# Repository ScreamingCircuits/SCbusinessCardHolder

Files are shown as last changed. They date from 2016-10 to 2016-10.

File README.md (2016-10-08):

# SCbusinessCardHolder
Screaming Circuits business card holder, V2.1

The Screaming Circuits business card holder is a multi-function device intended for your amusement and as a demonstration of our workmanship.

After soldering in the pin headers, attaching the rubber feet, and inserting the batteries, it’s ready to go. Place it on your desk and put about ten business cards in. When someone takes a card (or if you pound on your keyboard hard enough) some of the LEDs will flash.

If you tip it up, so that the LEDs run along the bottom, it will act as a spirit level, and as a short ruler. It’s not angle calibrated. Doing so is up to you. 

The microcontroller fitted is of the Microchip PIC18F46K22 family. The initial version was produced with a PIC18F43K22 – the same, but with less FLASH and SRAM. The accelerometer is a Freescale MMA8452Q. The schematic and layout were created with EagleCAD. The code was written and compiled with Microchip XC8 in Mplab-X.

One of the pin headers is connected to the I2C and SPI bus pins on the MCU. The other is connected to the Microchip ICSP (in circuit serial programming) pins on the MCU. Button Usr 1 is connected to I/O pin RB4, and Usr 2 is connected to RB5.

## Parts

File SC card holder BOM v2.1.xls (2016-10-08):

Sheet: BOM
Item # | Qty | Ref Des | Manufacturer | Manf part num | DigiKey Part number | Description | Package | Type | Side | Notes | Qty 1 | $ Ext | Qty 550 | Qty needed @550 | Ord Qty | $ Ext
1 | 1 | U1 | Microchip | PIC18F43K22-I/MV | PIC18F43K22-I/MV-ND | MCU | UQFN40 | BGA | Top |  | 2.29 | 2.29 | 1.9 | 550 | 600 | 1140.00
2 | 1 | U2 | Freescale | MMA8452QR1 | MMA8452QR1CT-ND | Accelerometer | QFN16 | BGA | Top |  | 1.43 | 1.43 | 1.02 | 550 | 600 | 612.00
3 | 10 | D1, D3, D5, D7, D9, D11, D13, D15, D17, D19 | Panasonic | LNJ247W82RA | LNJ247W82RACT-ND | LED red | 0402 | SMT | Top |  | 0.46 | 4.60 | 0.0936 | 5500 | 6000 | 561.60
4 | 9 | D2, D4, D6, D8, D10, D12, D14, D16, D18 | Panasonic | LNJ347W83RA | LNJ347W83RACT-ND | LED green | 0402 | SMT | Top |  | 0.46 | 4.14 | 0.0936 | 4950 | 5500 | 514.80
5 | 5 | C1, C2, C3, C4, C5 | Taiyo | LMK105BJ104KV-F | 587-1227-1-ND | .1uf | 0402 | SMT | Top |  | 0.10 | 0.50 | 0.00325 | 2750 | 3000 | 9.75
6 | 1 | C6 | Samsung | CL05A475MQ5NRNC | 1276-1056-1-ND | 4.7uf | 0402 | SMT | Top |  | 0.21 | 0.21 | 0.0485 | 550 | 600 | 29.10
7 | 19 | R1-R19 | Stackpole | RMCF0402JT180R | RMCF0402JT180RCT-ND | 180 ohms | 0402 | SMT | Top |  | 0.10 | 1.90 | 0.00173 | 10450 | 12000 | 20.76
8 | 3 | R20, R21, R22 | Stackpole | RMCF0402JT10K0 | RMCF0402JT10K0CT-ND | 10K | 0402 | SMT | Top |  | 0.10 | 0.30 | 0.00328 | 1650 | 2000 | 6.56
9 | 1 | S1 | C&K Components | JS202011SCQN | 401-2002-1-ND | DPDT switch |  | SMT | Top |  | 0.46 | 0.46 | 0.3031 | 550 | 500 | 151.55
10 | 2 | S2, S3 | C&K Components | PTS645SK50SMTR92 LFS | CKN9087CT-ND | Momentary push |  | SMT | Top |  | 0.25 | 0.50 | 0.13125 | 1100 | 1200 | 157.50
11 | 2 | B1, B2 | MPD | BK-883 | BK-883-ND | 2032 holder |  | SMT | Bottom |  | 0.35 | 0.70 | 0.2448 | 1100 | 1200 | 293.76
12 | 2 | H1, H2 | Sullins | PREC006SFAN-RC | S1212EC-06-ND | 1x6 header ICSP |  | DNS | Top |  | 0.20 | 0.40 | 0.11586 | 1100 | 1200 | 139.03
13 | 4 | F1, F2, F3, F4 | 3M | SJ61A1 | SJ5746-0-ND | Rubber foot |  | DNS | Bottom |  | 0.10 | 0.39 | 0.0787 | 2200 | 2400 | 188.88
14 | 2 | Batt1, Batt2 | Energizer | CR2032VP | N189-ND | CR2032 battery |  | DNS | Bottom |  | 0.33 | 0.66 | 0.18411 | 1100 | 1200 | 220.93
 |  |  |  |  |  | PCB 3.5" x 1.65" |  |  |  |  |  | 0.00
 |  |  |  |  |  |  |  |  |  |  | Total parts, Qty 1 | 18.48 |  | Total parts, Qty 550 | 7.36 | 4046.22
 | Blue = purchase, but don't install |  |  |  |  |  |  | Assembly quote summary
 |  |  |  |  |  |  | BOM line items | 11
 | Note that item #13, the 3M feet only come in sheets of 144 |  |  |  |  |  | BGA | 2
 |  |  |  |  |  |  | SMT | 52
 |  |  |  |  |  |  | Thru-hole | 0
 |  |  |  |  |  |  | Total | 54

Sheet: LED
System V | 3
Diode drop | 0.385
 | 2.615
LED V | 1.95
C | 0.0036 | Max LED C | 0.0828
R V | 0.665
R Ohm | 184.7222222

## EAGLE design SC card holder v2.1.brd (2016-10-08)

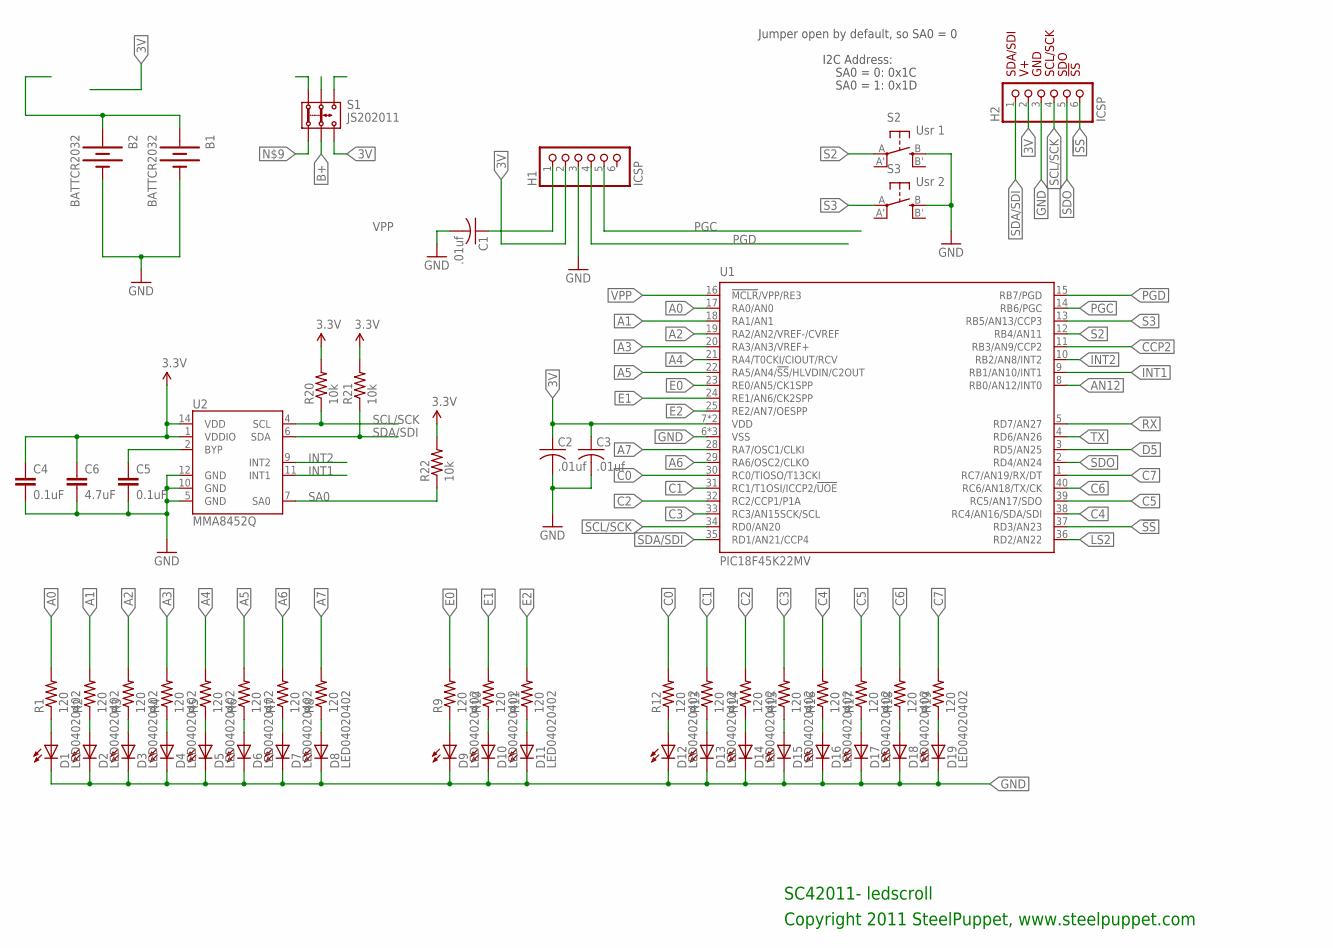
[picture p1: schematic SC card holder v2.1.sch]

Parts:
B1, B2: BATTCR2032; BATT_2032_SMT
C1, C2, C3: .01uf; C0402K
C4, C5: 0.1uF; 0402-CAP
C6: 4.7uF; 0402-CAP
D1, D2, D3, D4, D5, D6, D7, D8, D9, D10, D11, D12, D13, D14, D15, D16, D17, D18, D19: LED04020402; LED0402
H1, H2: ICSP; 1X06-S
R1, R2, R3, R4, R5, R6, R7, R8, R9, R10, R11, R12, R13, R14, R15, R16, R17, R18, R19: 120; R0402
R20, R21, R22: 10k; 0402-RES
S1: JS202011; JS202011SMT
S2: Usr 1; EVQ-Q2
S3: Usr 2; EVQ-Q2
U1: PIC18F45K22MV; QFN40-5X5
U2: MMA8452Q; QFN-16_0.5MM

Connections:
3V: C2.1, C3.1, C4.1, C6.1, H1.2, H2.2, R20.2, R21.2, R22.2, S1.3 (3.2), S1.4 (3.1), U1.7 (VDD), U1.26 (VDD), U2.1 (VDDIO), U2.14 (VDD)
!SS: H2.6, U1.37 (RD3/AN23)
A0: R1.2, U1.17 (RA0/AN0)
A1: R2.2, U1.18 (RA1/AN1)
A2: R3.2, U1.19 (RA2/AN2/VREF-/CVREF)
A3: R4.2, U1.20 (RA3/AN3/VREF+)
A4: R5.2, U1.21 (RA4/T0CKI/CIOUT/RCV)
A5: R6.2, U1.22 (RA5/AN4/!SS!/HLVDIN/C2OUT)
A6: R7.2, U1.29 (RA6/OSC2/CLKO)
A7: R8.2, U1.28 (RA7/OSC1/CLKI)
AN12: U1.8 (RB0/AN12/INT0)
B+: B1.1 (+), B1.3 (+), B2.1 (+), B2.3 (+), S1.2 (2.2), S1.5 (2.1)
BYP: C5.1, U2.2 (BYP)
C0: R12.2, U1.30 (RC0/TIOSO/T13CKI)
C1: R13.2, U1.31 (RC1/T1OSI/ICCP2/!UOE)
C2: R14.2, U1.32 (RC2/CCP1/P1A)
C3: R15.2, U1.33 (RC3/AN15SCK/SCL)
C4: R16.2, U1.38 (RC4/AN16/SDA/SDI)
C5: R17.2, U1.39 (RC5/AN17/SDO)
C6: R18.2, U1.40 (RC6/AN18/TX/CK)
C7: R19.2, U1.1 (RC7/AN19/RX/DT)
CCP2: U1.11 (RB3/AN9/CCP2)
D5: U1.3 (RD5/AN25)
E0: R9.2, U1.23 (RE0/AN5/CK1SPP)
E1: R10.2, U1.24 (RE1/AN6/CK2SPP)
E2: R11.2, U1.25 (RE2/AN7/OESPP)
GND: B1.2 (-), B2.2 (-), C1.2, C2.2, C3.2, C4.2, C5.2, C6.2, D1.C, D2.C, D3.C, D4.C, D5.C, D6.C, D7.C, D8.C, D9.C, D10.C, D11.C, D12.C, D13.C, D14.C, D15.C, D16.C, D17.C, D18.C, D19.C, H1.3, H2.3, S2.B (S), S3.B (S), U1.6 (VSS), U1.27 (VSS), U1.41 (VSS), U2.5 (GND), U2.10 (GND), U2.12 (GND)
INT1: U1.9 (RB1/AN10/INT1), U2.11 (INT1)
INT2: U1.10 (RB2/AN8/INT2), U2.9 (INT2)
LS2: U1.36 (RD2/AN22)
unnamed: D1.A, R1.1
unnamed: D2.A, R2.1
unnamed: D3.A, R3.1
unnamed: D4.A, R4.1
unnamed: D9.A, R9.1
unnamed: D10.A, R10.1
unnamed: D11.A, R11.1
unnamed: D13.A, R13.1
unnamed: D14.A, R14.1
unnamed: D15.A, R15.1
unnamed: D12.A, R12.1
unnamed: D6.A, R6.1
unnamed: D7.A, R7.1
unnamed: D16.A, R16.1
unnamed: D17.A, R17.1
unnamed: D8.A, R8.1
unnamed: D5.A, R5.1
unnamed: D18.A, R18.1
unnamed: D19.A, R19.1
PGC: H1.5, U1.14 (RB6/PGC)
PGD: H1.4, U1.15 (RB7/PGD)
RX: U1.5 (RD7/AN27)
S2: S2.A, U1.12 (RB4/AN11)
S3: S3.A, U1.13 (RB5/AN13/CCP3)
SA0: R22.1, U2.7 (SA0)
SCL/SCK: H2.4, R20.1, U1.34 (RD0/AN20), U2.4 (SCL)
SDA/SDI: H2.1, R21.1, U1.35 (RD1/AN21/CCP4), U2.6 (SDA)
SDO: H2.5, U1.2 (RD4/AN24)
TX: U1.4 (RD6/AN26)
VPP: C1.1, H1.1, U1.16 (!MCLR!/VPP/RE3)

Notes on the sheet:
SC42011- ledscroll
Copyright 2011 SteelPuppet, www.steelpuppet.com
SDA/SDI
GND
SCL/SCK
SDO
!SS
I2C Address:
SA0 = 0: 0x1C
SA0 = 1: 0x1D
Jumper open by default, so SA0 = 0

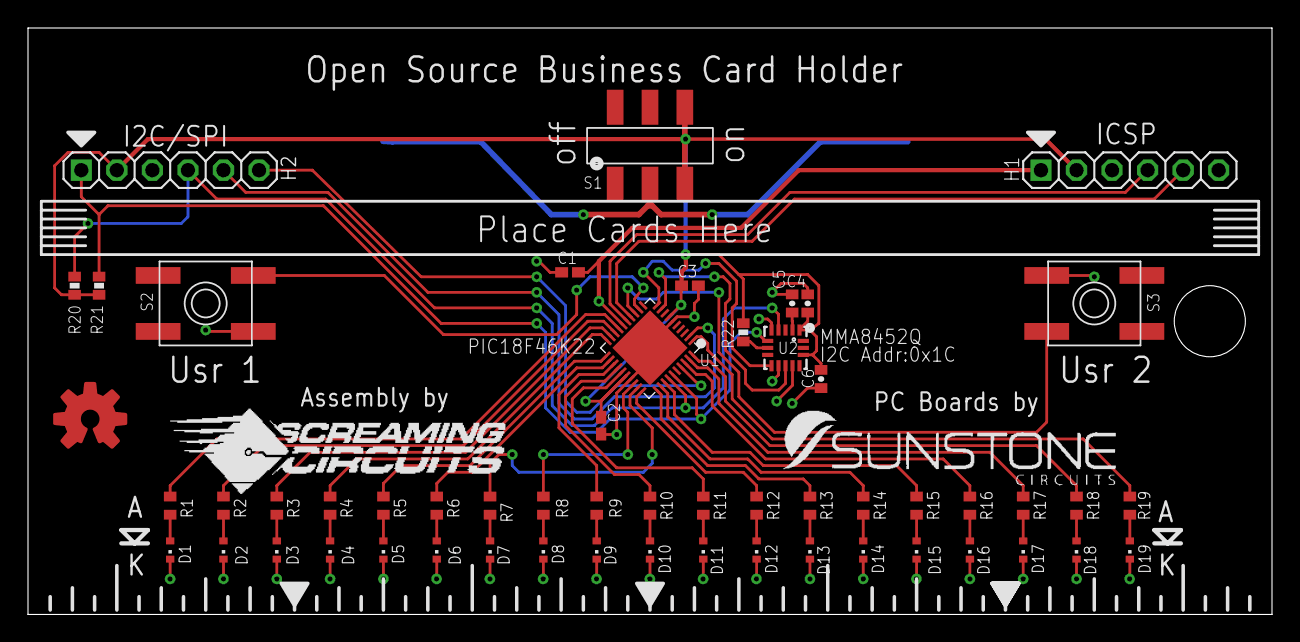
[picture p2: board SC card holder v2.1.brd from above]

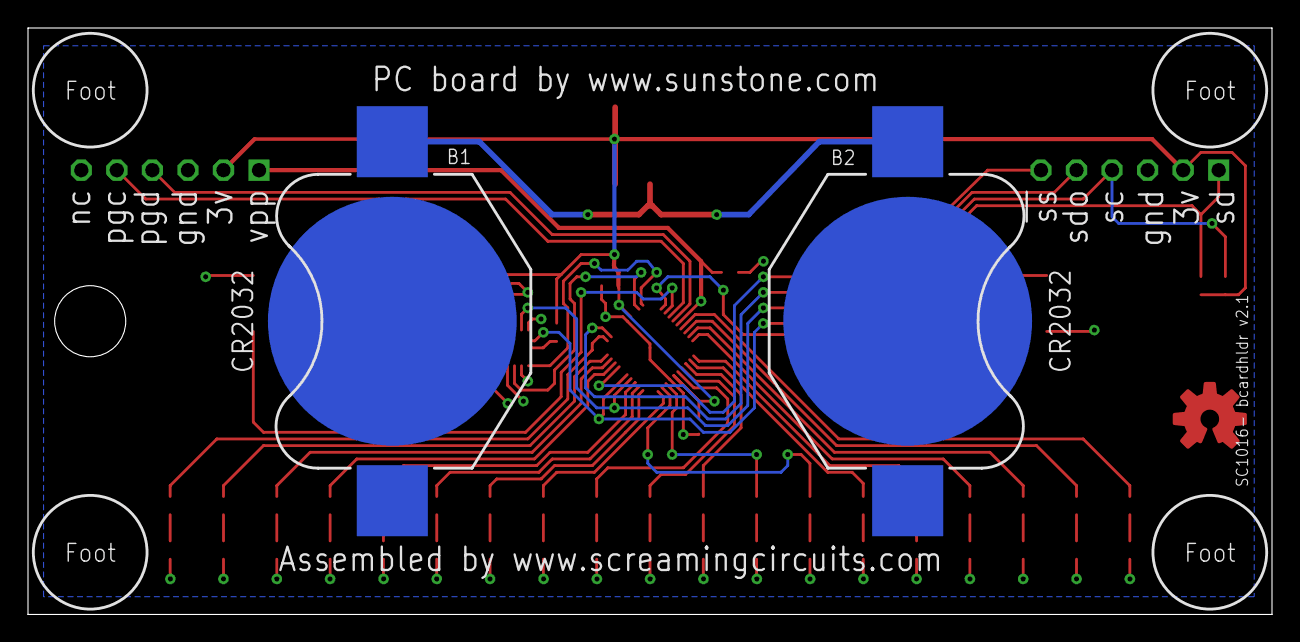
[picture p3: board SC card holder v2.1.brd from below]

Board: 2 copper layers, 88.9 x 41.9 mm, 59 parts (2 on the bottom side), 54 nets.

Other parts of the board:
U$1: SUNSTONE-LOGO
U$2: OSHWLOGO_TOP_0.2
U$3: SC-LOGO

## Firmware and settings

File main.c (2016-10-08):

// ##########################################################################
// ##########################################################################
// MicroBot IR sensor balance test
//
// copyright 2013, Steelpuppet / Duane Benson
// Started 4/18/2012
//
// Controls one motor H-Bridge
//
// Communicates via by I2C
// PIC18F25K50 MCU
//
//
// Edit history:
//
// ********************************************

// ####
// #### Project specific notes
// ####

// ####
/*
 * File:   main.c
 * Author: Duane
 *
 * Created on February 21, 2013, 12:06 PM
 */
// #### #### #### #### #### #### #### #### #### #### #### #### #### ####
// #### Defines
// #### #### #### #### #### #### #### #### #### #### #### #### #### ####

/******************************************************************************/
/* Files to Include                                                           */
/******************************************************************************/

#include <xc.h>        /* XC8 General Include File */
#include "globals.h"
#include "system.h"        /* System funct/params, like osc/peripheral config */
#include "user.h"          /* User funct/params, such as InitApp */
#include "configuration_bits.c"

/******************************************************************************/
/* User Global Variable Declaration                                           */
/******************************************************************************/

/* i.e. uint8_t <variable_name>; */

/******************************************************************************/
/* Main Program                                                               */
/******************************************************************************/


void main(void)
{
    int x;
    char PULSEdata, TRANSdata;

    /* Configure the oscillator for the device */
    ConfigureOscillator();

    /* Initialize I/O and Peripherals for application */
    InitApp();

    // Test patterns
    if (!PORTBbits.RB4 && !PORTBbits.RB5) { // Bothe Usr1 and Usr2 held at start up: All LEDs on
        LED0 = 1;
        LED1 = 1;
        LED2 = 1;
        LATA = 0xff;
        LATC = 0xff;
        delayLong(10);
        while (PORTBbits.RB5);
    } else if (!PORTBbits.RB4) {    // Usr1 held at start: all blue LEDs on
        LED1 = 1;
        LATA = 0xAA;
        LATC = 0x55;
        delayLong(10);
        while (PORTBbits.RB5);
    } else if (!PORTBbits.RB5) {    // Usr2 held at start: all red LEDs on
        LED0 = 1;
        LED2 = 1;
        LATA = 0x55;
        LATC = 0xAA;
        delayLong(10);
        while (PORTBbits.RB5);
    }

    LATA = 0x00;
    LATC = 0x00;

    LED1 = 1;
    for (x = 0; x < 10; x++){
        LED0 = !LED0;
        LED1 = !LED1;
        LED2 = !LED2;
        delayLong(1);
    }

    LED0 = 0;
    LED1 = 0;
    LED2 = 0;

    MMAdata = readRegister(0x0D);  // Read WHO_AM_I register
    if (MMAdata == 0x2A) { // WHO_AM_I should always be 0x2A
        initMMA8452(2, 0);  // init the accelerometer if communication is OK
    } else {
        LATA = MMAdata;
        while(1) ; // Loop forever if communication doesn't happen
    }
    
    RBIF = 0;           // Clear flags
    INT1IF = 0;
    INT2IF = 0;
    Usr1 = 0;
    Usr2 = 0;
    Int1 = 0;
    Int2 = 0;

    INTCONbits.GIE = 1;

    while (1) {
        if (Usr1) {
            flashAllInward(1);
            flashAllOutward(1);
            flashAllInward(1);
            flashAllOutward(1);
            Usr1 = 0;
        } else if (Usr2) {
            bubbleGum(6);
            Usr2 = 0;
        } else if (Int1) {
            flashAllOutward(1);
            Int1 = 0;
        } else if (Int2) {
            if ((ACTdataP & 0b01000000) == 0b01000000) {    // Z axis
                allOn(5);
                if ((ACTdataP & 0b00000100) == 0b00000100) {
                    flashLeft(2);
                } else {
                    flashRight(2);
                }
            } else if ((ACTdataP & 0b00100000) == 0b00100000) {  // Y axis
                allRed(5);
                if ((ACTdataP & 0b00000010) == 0b00000010) {
                    flashLeft(2);
                } else {
                    flashRight(2);
                }
            } else if ((ACTdataP & 0b00010000) == 0b00010000) { // X axis
                allBlue(5);
                if ((ACTdataP & 0b00000001) == 0b00000001 ) {
                    flashLeft(2);
                } else {
                    flashRight(2);
                }
            } else {
                flashAllInward(1);
            }
            Int2 = 0;
        } else {
            Sleep();
        }
    }
}

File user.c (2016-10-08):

/******************************************************************************/
/* Files to Include                                                           */
/******************************************************************************/

#include <xc.h>        /* XC8 General Include File */
#include "globals.h"
#include "user.h"
#include "system.h"

/******************************************************************************/
/* User Functions                                                             */
/******************************************************************************/

/* <Initialize variables in user.h and insert code for user algorithms.> */

void InitApp(void)
{
    /* TODO Initialize User Ports/Peripherals/Project here */
    TRISA = 0x00;
    TRISB = 0x00;
    TRISC = 0x00;
    TRISD = 0x00;
    TRISE = 0x00;

    LATA  = 0x00;
    LATB  = 0x00;
    LATC  = 0x00;
    LATD  = 0x00;
    LATE  = 0x00;

    ANSELA = 0x00;
    ANSELB = 0x00;
    ANSELC = 0x00;
    ANSELD = 0x00;
    ANSELE = 0x00;

    // Portsset to input for input switches and interrupts
    TRISB   |= 1 << 5;      // RB5 is input: Usr 2
    TRISB   |= 1 << 4;      // RB4 is input: Usr 1
    TRISB   |= 1 << 1;      // RB1 is input: Int 1 from accelerometer
    TRISB   |= 1 << 2;      // RB2 is input: Int 2 from accelerometer

    // Usr1 and Usr2 are normally-open active low. They need to pull-up
    WPUB4 = 1;              // Weak pull-up for RB4 / S2 / Usr 1
    WPUB5 = 1;              // Weak pull-up for RB5 / S3 / Usr 2

    // MMA8452 is set up with open drain, active-low interrupt lines
    //WPUB0 = 0;              // Weak pull-up for Int1
    WPUB1 = 0;              // Weak pull-up for Int1
    WPUB2 = 0;              // Weak pull-up for Int2
    RBPU = 0;               // 0 = enable pull-ups on PORTB, provided individual WPUB bits are set

    // Interrupts
    IPEN  = 0;              // Disable Interrupt prioritoes, as they are not needed
    INTCON = 0b00000000;    // Start with everything cleared

    // MMA8452 is set up with push-pull, active-high interrupt lines
    INTEDG1 = 1;            // Int1 pin interrupt on: 1 = rising edge, 0 = falling edge
    INTEDG2 = 1;            // Int2 pin interrupt on: 1 = rising edge, 0 = falling edge

    IOCBbits.IOCB4 = 1;     // Enable IOC on pin RB4
    IOCBbits.IOCB5 = 1;     // Enable IOC on pin RB5

    RBIF = 0;               // Clear interrupt flags
    INT1IF = 0;
    INT2IF = 0;

    INT1IE = 1;             // Interrupt pin 1: Accelerometer interrupt
    INT2IE = 1;             // Interrupt pin 2: Accelerometer interrupt

    RBIE = 1;               // Port B int on change: RB4 and RB5 are Usr 1 and Usr 2

    // Set I2C pins as inputs
    TRISD |= 1 << 0;        // RD0 = SCL2/SCK2
    TRISD |= 1 << 1;        // RD1 = SDA2/SDI2

    SSP2ADD = 0x9F;         // 100 KHz I2C clock with 64 MHz system clock
    SSP2STATbits.SMP = 1;   // Slew off
    SSP2CON1bits.SSPEN = 1; // Enable I2C
    SSP2CON1 = 0b00101000;

// setting and clearing the appropriate SSPxM bits in the SSPxCON1 register and by setting the SSPxEN bit.
}


// Delay time in multiples of 10 ms
void delayLong(unsigned long x) {
    unsigned long i;
    for (i = 0; i < x; i++) {
        __delay_ms(10);
    }
}


void flashAllInward(int x) {

    for (int i = 0; i < x; i++) {
        LED0 = 0;
        LED1 = 1;
        LED2 = 0;
        LATA = 0b00000001;
        LATC = 0b10000000;
        delayLong(1);
        for (int k = 0; k < 8; k++) {
            LATA = LATA << 1;
            LATC = LATC >> 1;
            LED0 = !LED0;
            LED1 = !LED1;
            LED2 = !LED2;
            delayLong(1);
        }
    }
    LED0 = 0;
    LED1 = 0;
    LED2 = 0;
}

void flashAllOutward(int x) {

    for (int i = 0; i < x; i++) {
        LED0 = 1;
        LED1 = 0;
        LED2 = 1;
        LATA = 0b10000000;
        LATC = 0b00000001;
        delayLong(1);
        for (int k = 0; k < 8; k++) {
            LATA = LATA >> 1;
            LATC = LATC << 1;
            LED0 = !LED0;
            LED1 = !LED1;
            LED2 = !LED2;
            delayLong(1);
        }
    }
    LED0 = 0;
    LED1 = 0;
    LED2 = 0;
}


void bubbleGum(int x) {
    for (int i = 0; i < x; i++) {
        LATC = 0b01010101; // blue
        delayLong(2);
        LATA = 0b10101010; // red
        delayLong(5);

        LATA = 0b01010101; // blue
        delayLong(2);
        LATC = 0b10101010; // red
        delayLong(5);
    }
    LATA = 0x00;
    LATC = 0x00;
}


void allOn(int x) {
    LED0 = 1;
    LED1 = 1;
    LED2 = 1;
    LATA = 0xff;
    LATC = 0xff;

    delayLong(x);

    LED0 = 0;
    LED1 = 0;
    LED2 = 0;
    LATA = 0x00;
    LATC = 0x00;
}


void allBlue(int x) {
    LED1 = 1;
    LATA = 0xAA;
    LATC = 0x55;

    delayLong(x);

    LED0 = 0;
    LED1 = 0;
    LED2 = 0;
    LATA = 0x00;
    LATC = 0x00;
}

void allRed(int x) {
    LED0 = 1;
    LED2 = 1;
    LATA = 0x55;
    LATC = 0xAA;

    delayLong(x);

    LED0 = 0;
    LED1 = 0;
    LED2 = 0;
    LATA = 0x00;
    LATC = 0x00;
}

void allLeft(int x) {
    LATA = 0xFF;
    delayLong(x);
    LATA = 0x00;
}


void allRight(int x) {
    LATC = 0xFF;
    delayLong(x);
    LATC = 0x00;
}

void flashLeft(int x) {
    LATA = 0xFF;
    __delay_ms(10);
    __delay_ms(10);
    for (int i = 0; i < x; i++) {
        //LATA = 0b10000000;
        delayLong(1);
        for (int k = 0; k < 8; k++) {
            LATA = LATA >> 1;
            delayLong(1);
        }
    }
    LATA = 0x00;
}


void flashRight(int x) {
    LATC = 0xFF;
    __delay_ms(10);
    __delay_ms(10);
        for (int i = 0; i < x; i++) {
        //LATC = 0b00000001;
        delayLong(1);
        for (int k = 0; k < 8; k++) {
            LATC = LATC << 1;
            delayLong(1);
        }
    }
    LATC = 0x00;
}

// MMA8452Q functions

// Initialize the MMA8452 registers
// See the many application notes for more info on setting all of these registers:
// http://www.freescale.com/webapp/sps/site/prod_summary.jsp?code=MMA8452Q
// Feel free to modify any values, these are settings that work well for me.
void initMMA8452(char fsr, char dataRate){
  MMA8452Standby();  // Must be in standby to change registers

// Set up transients
  writeRegister(0x1D, 0b00011111);  //
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
